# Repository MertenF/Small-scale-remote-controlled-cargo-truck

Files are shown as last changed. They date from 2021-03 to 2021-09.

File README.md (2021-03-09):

# Small-scale-remote-controlled-cargo-truck
Maarten Herremans & Merten Fermont

## Omschrijving
Een op afstand bestuurbare cargo truck waarmee een bak bier vervoerd kan worden.
De afstandsbediening en de truck zelf zijn de 2 grote blokken van het project. Beiden zijn gecentreerd rond de STM32F303R68T microcontroller.

## Truck
De truck beweegt zich door middel van 2 BLDC motoren en stuurt met een servo motor.
Er zijn voor en achterlichten aanwezig voor in het donker, samen met pinkers. Om in het donker goed te zien waar de truck rijd is er powerled als fare voorzien. Een toeter is ook voorzien.
Dit zal allemaal gevoed worden door een 5s13p batterijpack van lithiumcellen, beveiligd met een BMS.

## Afstandsbediening
Het afstandsbediening bevat 2 joysticks om gas te geven of te remmen en te sturen. Een aantal drukknoppen om de lichten te bedienen en een rotary encoder om de helderheid van de fare in te stellen.
De communicatie gebeurd op de 2.4GHz band met de NRF24L01+ chip

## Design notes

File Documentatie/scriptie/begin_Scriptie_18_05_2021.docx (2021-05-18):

# Small-scale Remote Controlled RC Car

# Voorwoord

# Inleiding

Het doel van het project is om een klein transport wagentje en een afstandsbediening hiervoor zelf te maken. Het proces zal voornamelijk het design van de verschillende PCB’s inhouden en hierna de software implementatie.

# Blokschemas

## Controller

De inputs van de controller zijn een aantal knoppen voor de verschillende functies.
De joysticks dienen voor te kunnen sturen.
De Potmeter kan een

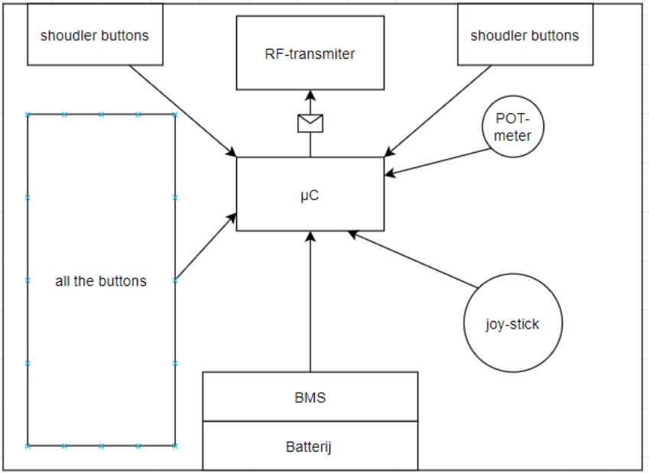
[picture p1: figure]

Figuur 1: blokschema afstandsbediening

## Truck

De main PCB bevind zich op de truck. Hiervan gaan nog de lichten op aparte kleinere PCBtjes komen. Deze licht PCBtjes zijn 4 keer hetzelfde buiten de kleur van de LED.
De main PCB bestaat voornamelijk uit het power delivery systeem met de 5 buckconverters en de BMS.

De ESC is en aparte module waarvan der power van de BMS wordt aangesloten en de signaal kabel van aan de STM µC.

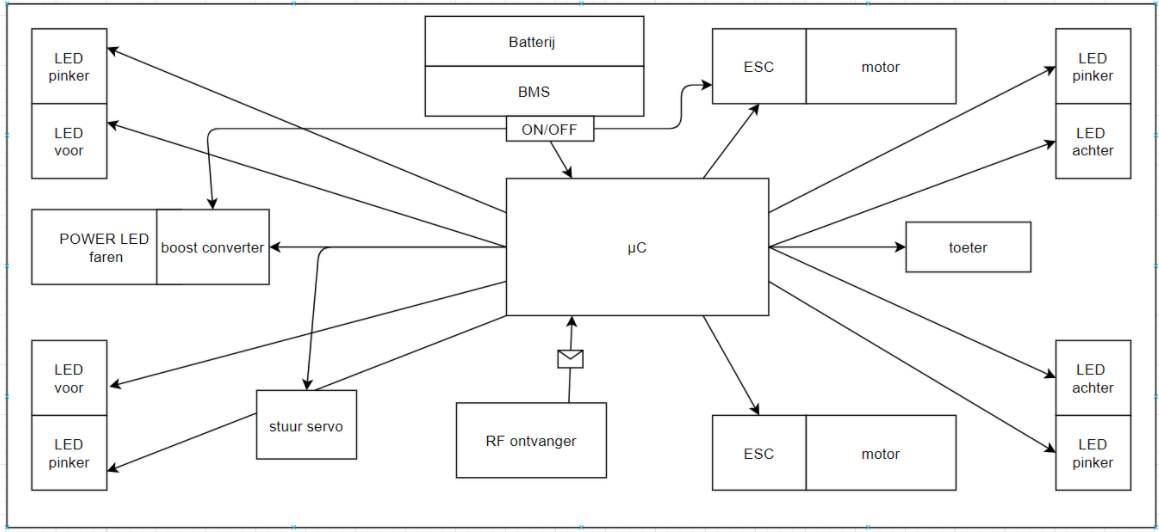
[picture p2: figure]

Figuur 2: blokschema truck

## Spanning niveaus

Er zijn 5 verschillende spanning niveaus nodig voor alle verschillende componenten.
Hierdoor zullen we 4 verschillende Bucks nodig hebben op het main board.

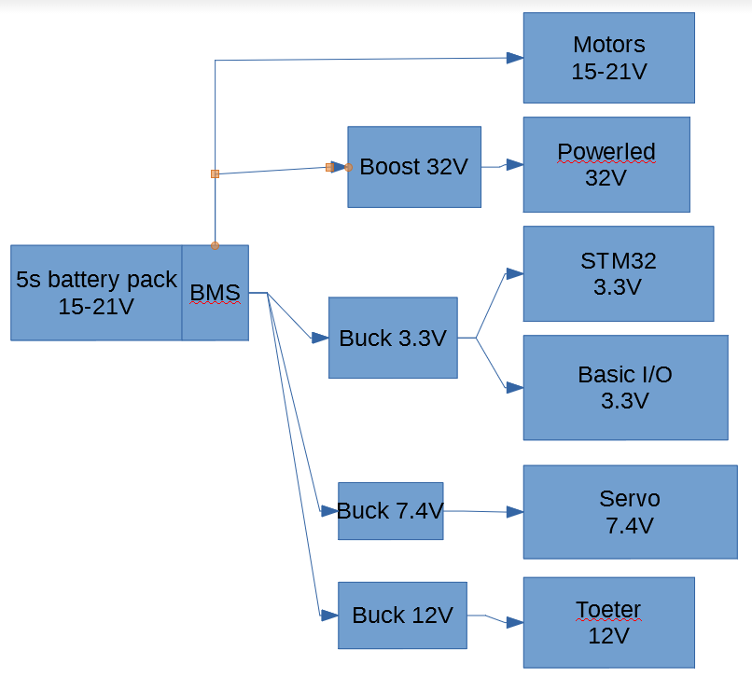
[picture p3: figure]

Figuur 3: blokschema voltage levels

# Hardware

## Schematics

### Electrical

In dit hoofdstuk bevinden zich alle elektrische schemas voor de verschillende PCB’s

#### Controller

De afstands bediening moet alle inputs van de gebruiker inlezen en dan verzenden naar de PCB in de truck.

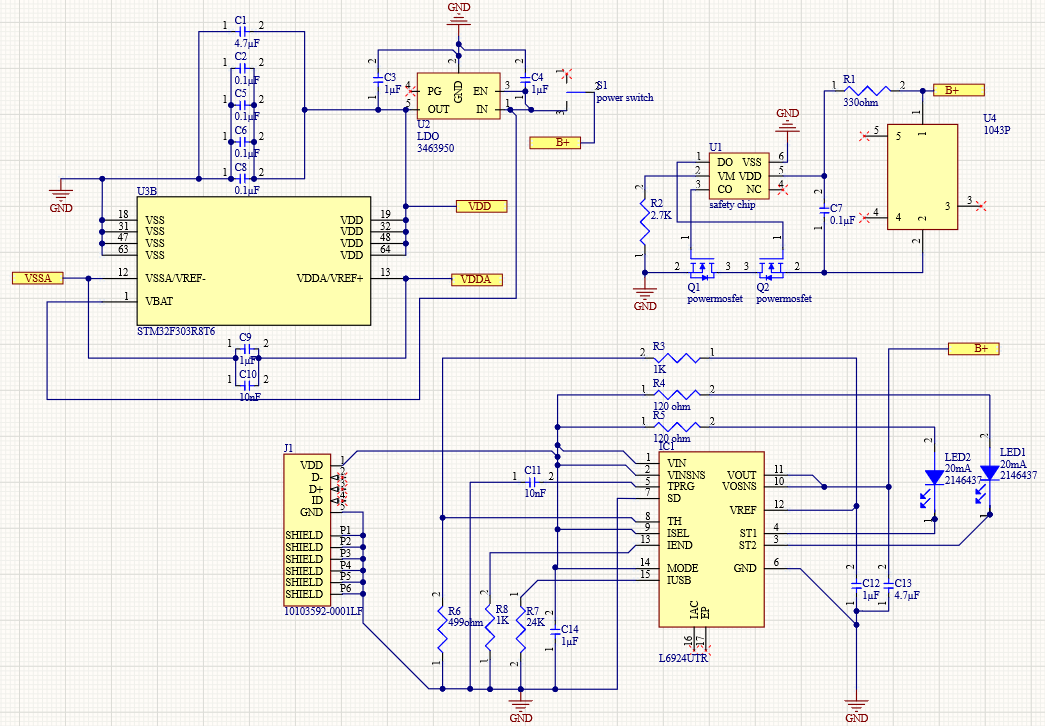
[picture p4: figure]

Figuur 4: afstandsbediening power schema

Op het power schema is het power deel van de STM32F3 aan de linkerkant.
Rechts vanboven bevind zich de batterij en de BMS chip.
vanonder links is de micro USB poort en rechts vanonder is de oplader chip voor de batterij.
Er zijn feedback LED’s rechts vanonder die aangeven wat de oplaad status is.

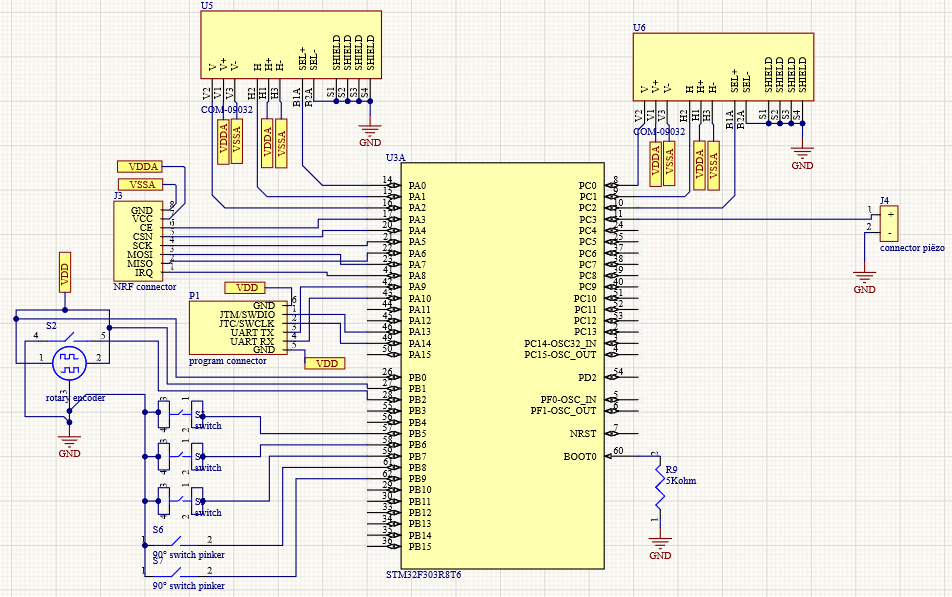
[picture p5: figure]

Figuur 5: afstandsbediening Input en Output

Het main input schema bevat al de GPIO aansluitingen aan de STM plus de nodige rand componenten.

#### Truck

### PCB

#### Controller

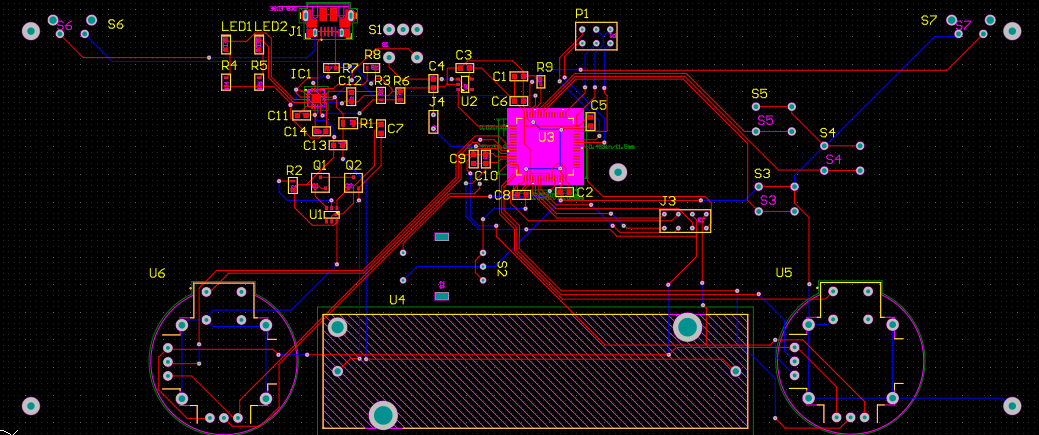
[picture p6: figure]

Figuur 6: PCB afstandsbediening

Links en rechts van onder bevinden zich de joysticks. Deze bevinden zich op deze locatie zodat ze ergonomisch goed zitten. Hetzelfde voor de schouder knoppen links en rechts vanboven.
De condensatoren staan valk naast de IC’s voor minimale EMS.
De batterij houder aan de onderkant had verticaal aan de achterkant geplaatst kunnen worden dit had veel plaats kunnen besparen en ervoor kunnen zorgen dat er veel minder open ruimte is.

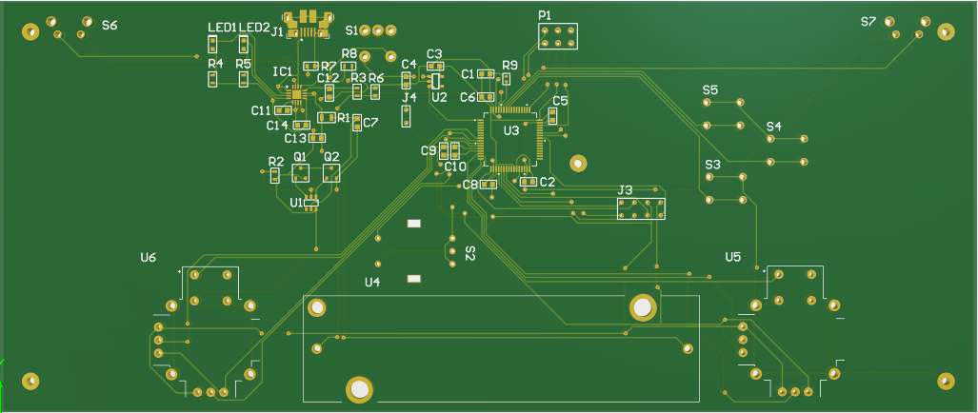
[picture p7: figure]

Figuur 7: 3D board layout afstandsbediening

#### Truck

#### Lichten

## RF module

NRF24L01+

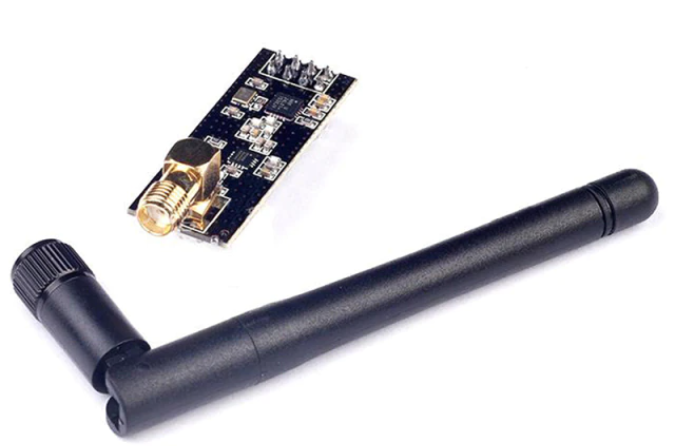
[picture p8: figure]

Voor de draadloze communicatie op 2.4GHz

## Micro controler

STM32F303R8T6

## Drive

### ESC

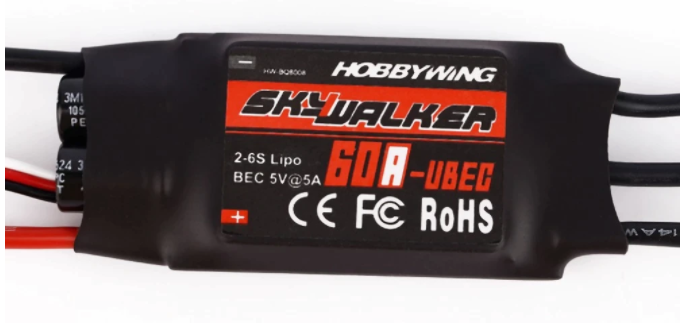
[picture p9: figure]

Specificities:
Constante Stroom: 60A
Burst Stroom (>10s): 80A
spanning: 2s-6s Lipo

### Motor

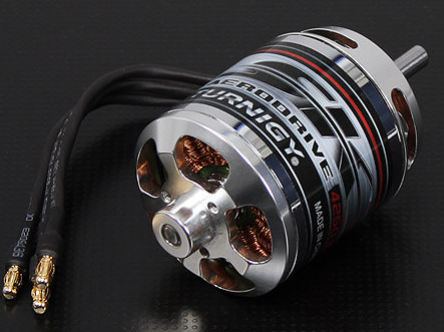
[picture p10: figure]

Specificities:
spanning: 4 ~ 5S Lipo
RPM / V: 410kv
interne weerstand: 0,026 Ohm
Max amperage: 55A
Max Power: 1310W

### Servo

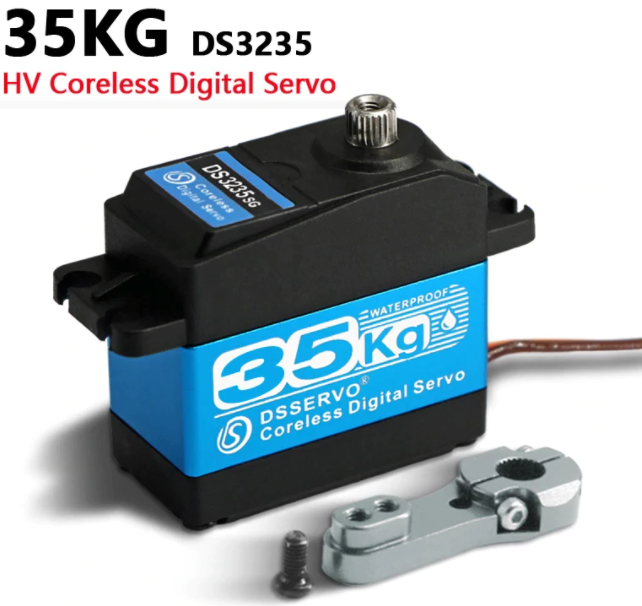
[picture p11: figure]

Spanning: 7.4 volt
rust stroom: 5mA
piek stroom: 2.3A
piek gewicht: 35 kilo

## Mechanische realisatie

### Band overbrenging

Ratio 1:4

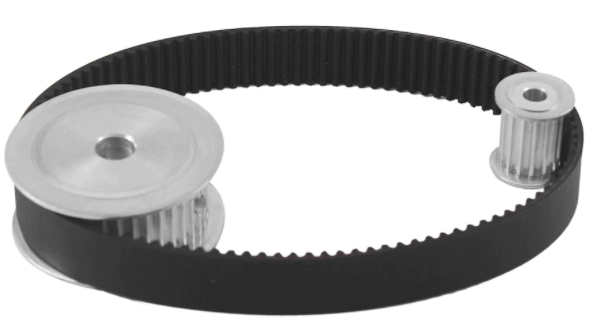
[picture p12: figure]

### Wielen

1/8 schaal wielen.

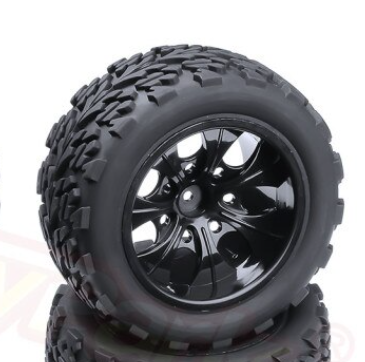
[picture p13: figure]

### Behuizing

# Software

## Testing modules

## Flowchart

## Logic

## I/O

### PWM

### I²C SPI

### RF

Eigen protocol
voor langere range dan enhanced shockburst

# Besluit

# Datasheets

# Bronnen

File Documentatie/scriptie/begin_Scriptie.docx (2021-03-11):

# Small-scale Remote Controlled RC Car

# Voorwoord

# inleiding

# Blokschemas

## Controller


## Truck


## Voltage levels


# Hardware

## Schematics

### Electrical

#### Controller

#### Truck

### PCB

#### Controller

#### Truck

### CAD

#### Controller

#### Truck

## RF module

NRF24L01+

## Micro controler

STM32F303R8T6

## Drive

### ESC

### Motor

### Servo

## Mechanische realisatie

### Band overbrenging

### Wielen

### Hexdrive

### Behuizing

# Software

## Testing modules

## Flowchart

## Logic

## I/O

### PWM

### I²C SPI

### RF

Eigen protocol
voor langere range dan enhanced shockburst

# Besluit

# Datasheets

# Bronnen

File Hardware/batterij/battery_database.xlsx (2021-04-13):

BATTERIJ | CHARGE Mah [@1.5A] | discharge [mAh@2A] | charging mohm start | charging mohm end | opmerking
A1 | 1328 | 1339 | 41 | 32
A2 | 1333 | 1314 | 49 | 28
A3 | 1319 | 1314 | 51 | 40
A4 | 1313 | 1315 | 49 | 30
A5 | 1315 | 1303 | 53 | 33
A6 | 1298 | 1319 | 35 | 27
A7 | 1268 | 1315 | 47 | 36 | cell 2de poging
A8 | 1260 | 1304 | 43 | 35
A9 | 1229 | 1306 | 43 | 34
B1 | 1241 | 1330 | 44 | 34
B2 | 1262 | 1299 | 44 | 32
B3 | 1272 | 1319 | 43 | 33 | in 2keer opegeladen
B4 | 1244 | 1276 | 41 | 32 | cell 2de poging
B5 | 1249 | 1275 | 48 | 37
B6 | 1244 | 1271 | 44 | 34
B7 | 1253 | 1281 | 36 | 28
B8 | 1254 | 1284 | 40 | 31
B9 | 1242 | 1266 | 48 | 34
C1 | 1247 | 1272 | 34 | 34
C2 | 1220 | 1274 | 50 | 28
C3 | 1270 | 1308 | 49 | 37
C4 | 1257 | 1291 | 49 | 37
C5 | 1258 | 1291 | 49 | 37
C6 | 1270 | 1298 | 40 | 31
C7 | 1259 | 1306 | 49 | 36
C8 | 1250 | 1285 | 43 | 34
C9 | 1271 | 1303 | 47 | 37
D1 | 1268 | 1302 | 46 | 36
D2 | 1299 | 1285 | 45 | 35
D3 | 1305 | 1295 | 52 | 32
D4 | 1248 | 1291 | 51 | 36
D5 | 1248 | 1299 | 46 | 36
D6 | 1304 | 1290 | 44 | 34
D7 | 1330 | 1303 | 43 | 34
D8 | 1266 | 1281 | 38 | 30
D9 | 1272 | 1296 | 39 | 31
E1 | 1262 | 1279 | 40 | 30
E2 | 1272 | 1293 | 40 | 30
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

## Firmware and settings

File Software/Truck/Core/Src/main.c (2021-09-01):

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
/* Includes ------------------------------------------------------------------*/
#include "main.h"

/* USER CODE BEGIN Includes */
#include <stdio.h>
#include <errno.h>
#include <sys/stat.h>
#include <sys/times.h>
#include <sys/unistd.h>

#include <stdbool.h>
/* USER CODE END Includes */

SPI_HandleTypeDef hspi2;
SPI_HandleTypeDef hspi3;

TIM_HandleTypeDef htim3;
TIM_HandleTypeDef htim4;

UART_HandleTypeDef huart2;
UART_HandleTypeDef huart3;

/* USER CODE BEGIN PV */
// NRF commando's
const uint8_t R_REGISTER = 0b00000000;
const uint8_t W_REGISTER = 0b00100000;
const uint8_t R_RX_PAYLOAD = 0b01100001;
const uint8_t W_TXPAYLOAD = 0b10100000;
const uint8_t FLUSH_TX = 0b11100001;
const uint8_t FLUSH_RX = 0b11100010;
const uint8_t REUSE_TX_PL = 0b11100011;
const uint8_t R_RX_PL_WID = 0b01100000;
const uint8_t W_ACK_PAYLOAD = 0b10101000;
const uint8_t W_TX_PAYLOAD_NOACK = 0b10110000;
const uint8_t NOP = 0b11111111;

// NRF registers
const uint8_t CONFIG = 0x00;
const uint8_t EN_AA = 0x01;
const uint8_t EN_RXADDR = 0x02;
const uint8_t SETUP_AW = 0x03;
const uint8_t SETUP_RETR = 0x04;
const uint8_t RF_CH = 0x05;
const uint8_t RF_SETUP = 0x06;
const uint8_t STATUS = 0x07;
const uint8_t OBSERVE_TX = 0x08;
const uint8_t RPD = 0x09;
const uint8_t RX_ADDR_P0 = 0x0A;
const uint8_t RX_ADDR_P1 = 0x0B;
const uint8_t RX_ADDR_P2 = 0x0C;
const uint8_t RX_ADDR_P3 = 0x0D;
const uint8_t RX_ADDR_P4 = 0x0E;
const uint8_t RX_ADDR_P5 = 0x0F;
const uint8_t TX_ADDR = 0x10;
const uint8_t RX_PW_P0 = 0x11;
const uint8_t RX_PW_P1 = 0x12;
const uint8_t RW_PW_P1 = 0x13;
const uint8_t RX_PW_P3 = 0x14;
const uint8_t RX_PW_P4 = 0x15;
const uint8_t RX_PW_P5 = 0x16;
const uint8_t FIFO_STATUS = 0x17;
const uint8_t DYNPD = 0x1C;
const uint8_t FEATURE = 0x1D;

#define servoMinAbs 1565 //minimum waarde servo
#define servoMaxAbs 7826
const uint32_t motorMin = 3130; //minimum waarde motor
const uint32_t motorMax = 6260;
uint32_t servoMin = (servoMinAbs+servoMaxAbs)/2-1000;
uint32_t servoMax = (servoMinAbs+servoMaxAbs)/2+1000;
uint8_t RecData[32] = {0};
uint8_t counter = 0;

struct IOs {
	bool Left_Button;
	bool Up_Button;
	bool Down_Button;
	bool Rotary_Button;
	bool Joy2_Button;
	bool FrontLeft_Button;
	bool FrontRight_Button;
	uint8_t Joy1_UpDown;
	uint8_t Joy2_UpDown;
	uint8_t Joy2_LeftRight;
} Status_IO;

uint8_t rxd[10] = {0};
uint8_t UART3_rxBuffer[13] = {0};

/* USER CODE END PV */

void SystemClock_Config(void);
static void MX_GPIO_Init(void);
static void MX_TIM3_Init(void);
static void MX_TIM4_Init(void);
static void MX_SPI2_Init(void);
static void MX_SPI3_Init(void);
static void MX_USART2_UART_Init(void);
static void MX_USART3_UART_Init(void);
/* USER CODE BEGIN PFP */
void Write8_Register_NRF(uint8_t, uint8_t);
uint8_t Read8_Register_NRF(uint8_t);
void CSN_Select(void);
void CSN_Deselect(void);
void Send_Data(uint8_t*);
void NRF_Setup(void);
void WriteX_Register_NRF(uint8_t, uint8_t*, uint8_t);
void Data_Receive(uint8_t*);
uint8_t isDataAvailable (uint8_t);

void Set_Servo_Angle(uint8_t);
void Set_Motor_Speed(uint8_t);
void Print_IO(void);

/* USER CODE END PFP */

/* USER CODE BEGIN 0 */
int _write(int file, char *ptr, int len) {
    HAL_StatusTypeDef xStatus;
    switch (file) {
    case STDOUT_FILENO: /*stdout*/
		xStatus = HAL_UART_Transmit(&huart2, (uint8_t*)ptr, len, HAL_MAX_DELAY);
		if (xStatus != HAL_OK) {
			errno = EIO;
			return -1;
		}
        break;
    case STDERR_FILENO: /* stderr */
		xStatus = HAL_UART_Transmit(&huart2, (uint8_t*)ptr, len, HAL_MAX_DELAY);
		if (xStatus != HAL_OK) {
			errno = EIO;
			return -1;
		}
        break;
    default:
        errno = EBADF;
        return -1;
    }
    return len;
}
/* USER CODE END 0 */

/**
  * @brief  The application entry point.
  * @retval int
  */
int main(void)
{
  /* MCU Configuration--------------------------------------------------------*/

  /* Reset of all peripherals, Initializes the Flash interface and the Systick. */
  HAL_Init();

  /* Configure the system clock */
  SystemClock_Config();

  /* Initialize all configured peripherals */
  MX_GPIO_Init();
  MX_TIM3_Init();
  MX_TIM4_Init();
  MX_SPI2_Init();
  MX_SPI3_Init();
  MX_USART2_UART_Init();
  MX_USART3_UART_Init();
  /* USER CODE BEGIN 2 */

  printf("starting up: ");


  HAL_UART_Receive_IT(&huart3, UART3_rxBuffer, 13);


  HAL_TIM_PWM_Start(&htim3, TIM_CHANNEL_1); //servo
  HAL_TIM_PWM_Start(&htim3, TIM_CHANNEL_2); //motor 1
  HAL_TIM_PWM_Start(&htim3, TIM_CHANNEL_3); //motor 2

  TIM3->CCR1 = (servoMin+servoMax)/2; //servo in het midden zetten
  TIM3->CCR2 = motorMin; //motors minimum power geven
  TIM3->CCR3 = motorMin;


  HAL_Delay(400); //ESC heeft bij opstarten een tijdje minimum signaal nodig
  //NRF_Setup();


  //HAL_TIM_PWM_Start(&htim4, TIM_CHANNEL_1); //toeter
  //HAL_TIM_PWM_Stop(&htim4, TIM_CHANNEL_1);
  //TIM4->CCR1 = 50; //0% duty cycle

  /* USER CODE END 2 */

  /* Infinite loop */
  /* USER CODE BEGIN WHILE */
  while (1)
  {
	  HAL_Delay(80);
	  //printf("\r\nwhile loop truck: %02X\r\n", counter++);


	  //Print_IO();


	  Set_Motor_Speed(Status_IO.Joy1_UpDown);
	  Set_Servo_Angle(Status_IO.Joy2_LeftRight);


	  if(Status_IO.Down_Button) {
		  //TIM4->CCR1 = 50;
	  } else {
		  //TIM4-> CCR1 = 0;
	  }
	  //get data
	  //setup data


    /* USER CODE END WHILE */

    /* USER CODE BEGIN 3 */
  }
  /* USER CODE END 3 */
}

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
/* USER CODE BEGIN 4 */

uint8_t Count13(uint8_t val) {
	if (val<13) {
		return val;
	} else {
		return (val-13);
	}
}

void HAL_UART_RxCpltCallback(UART_HandleTypeDef *huart)
{
	for(uint8_t i = 0; i<13; i++) {
		printf("%u ", UART3_rxBuffer[i]);
	} printf("\r\n");

	uint8_t i = 0;
	while (UART3_rxBuffer[Count13(i)] != 0x41 || UART3_rxBuffer[Count13(i+1)] != 0x41 || UART3_rxBuffer[Count13(i+2)] != 0x41) {
		i++;
	}
	//printf("bytes shifted: %u", i);

	Status_IO.Left_Button = UART3_rxBuffer[Count13(i+3)];
	Status_IO.Up_Button = UART3_rxBuffer[Count13(i+4)];
	Status_IO.Down_Button = UART3_rxBuffer[Count13(i+5)];
	Status_IO.Rotary_Button = UART3_rxBuffer[Count13(i+6)];
	Status_IO.Joy2_Button = UART3_rxBuffer[Count13(i+7)];
	Status_IO.FrontLeft_Button = UART3_rxBuffer[Count13(i+8)];
	Status_IO.FrontRight_Button = UART3_rxBuffer[Count13(i+9)];
	Status_IO.Joy1_UpDown = UART3_rxBuffer[Count13(i+10)];
	Status_IO.Joy2_UpDown = UART3_rxBuffer[Count13(i+11)];
	Status_IO.Joy2_LeftRight = UART3_rxBuffer[Count13(i+12)];

	//Print_IO();

    HAL_UART_Receive_IT(&huart3, UART3_rxBuffer, 13);
}

void Print_IO() {
	printf("IO status:\r\n");
	printf("Buttons: LB=%d, UB=%d, DB=%d, RB=%d, J2B=%d\r\n",
			Status_IO.Left_Button,
			Status_IO.Up_Button,
			Status_IO.Down_Button,
			Status_IO.Rotary_Button,
			Status_IO.Joy2_Button);

	printf("ADC: 1-UD=%u, 2-UD=%u, 2-LR=%u\r\n",
			Status_IO.Joy1_UpDown,
			Status_IO.Joy2_UpDown,
			Status_IO.Joy2_LeftRight);
}

void Read_Data() {
	//fill
}


void Set_Motor_Speed(uint8_t speed) {
	uint32_t signal = (motorMax-motorMin)*speed/255+motorMin;

	if (signal<motorMin) {
		printf("Motor signal to low: %lu\r\n", signal);
		signal = motorMin;
	} else if (signal > motorMax) {
		printf("Motor signal to high: %lu\r\n", signal);
		signal = motorMax;
	}

	TIM3->CCR2 = signal;
	TIM3->CCR3 = signal;
}

void Set_Servo_Angle(uint8_t angle) {
	uint32_t signal = (servoMax-servoMin)*angle/255+servoMin;

	if (signal<servoMin) {
		printf("Servo signal to low: %lu\r\n", signal);
		signal = servoMin;
	} else if (signal > servoMax) {
		printf("Servo signal to high: %lu\r\n", signal);
		signal = servoMax;
	}

	TIM3->CCR1 = signal;
}

uint8_t Read8_Register_NRF(uint8_t reg) {
	uint8_t data = 0;

	CSN_Select();
	HAL_SPI_Transmit(&hspi2, &reg, 1, 100);
	while(HAL_SPI_GetState(&hspi2) != HAL_SPI_STATE_READY);
	HAL_SPI_Receive(&hspi2, &data, 1, 100);
	CSN_Deselect();

	printf("Receive %02X: %02X\r\n", reg, data);
	return 0;
}

void Write8_Register_NRF(uint8_t reg, uint8_t data) {
	uint8_t buf[2];

	buf[0] = reg|W_REGISTER;
	buf[1] = data;

	CSN_Select();
	HAL_SPI_Transmit(&hspi2, buf, 2, 1000);
	CSN_Deselect();
}

void WriteX_Register_NRF(uint8_t reg, uint8_t *data, uint8_t size) {
	CSN_Select();

	uint8_t cmd = reg|W_REGISTER;

	HAL_SPI_Transmit(&hspi2, &cmd, 1, 100);
	HAL_SPI_Transmit(&hspi2, data, size, 1000);
	/*
	uint8_t sent[1+size];
	uint8_t cmd = reg|W_REGISTER;
	sent[0] = cmd;

	HAL_StatusTypeDef result;
	result = HAL_SPI_Transmit(&hspi2, sent, size+1, 1000);
	printf("Result: %u\r\n", result);
//	HAL_SPI_Transmit(&hspi1, &cmd, 1, 100);
//	HAL_SPI_Transmit(&hspi1, data, size, 1000);
*/



	CSN_Deselect();
}

uint8_t* ReadX_Register_NRF(uint8_t reg, uint8_t size) {
	uint8_t data[32] = {0};

	CSN_Select();
	HAL_SPI_Transmit(&hspi2, &reg, 1, 100);
	HAL_SPI_Receive(&hspi2, data, size, 1000);
	CSN_Deselect();

	for (uint8_t i = 0; i<size; i++) {
		printf("%02X ", i);
	}
	printf("\r\n");
	return 0;
}

void Send_Cmd(uint8_t cmd) {
	CSN_Select();
	HAL_SPI_Transmit(&hspi2, &cmd, 1, 100);
	CSN_Deselect();
}

void Send_Data(uint8_t *data) {

	uint8_t cmd = W_TXPAYLOAD;
	CSN_Select();
	HAL_SPI_Transmit(&hspi2, &cmd, 1, 100);
	HAL_SPI_Transmit(&hspi2, data, 32, 1000);
	CSN_Deselect();

	printf("observe tx");
	Read8_Register_NRF(OBSERVE_TX);

	printf("fifo status");
	uint8_t fifostatus = Read8_Register_NRF(FIFO_STATUS);
	// check the fourth bit of FIFO_STATUS to know if the TX fifo is empty
	if ((fifostatus&(1<<4)) && (!(fifostatus&(1<<3))))
		{
			printf("Fifo full\r\n");
			cmd = FLUSH_TX;
			Send_Cmd(cmd);
		} else {
			//printf("empty\r\n");
		}
}


uint8_t isDataAvailable (uint8_t pipenum)
{
	printf("Status ");
	uint8_t status = Read8_Register_NRF(STATUS);
	printf("FIFO_STATUS ");
	Read8_Register_NRF(FIFO_STATUS);

	if ((status&(1<<6))||1) //&&(status&(pipenum<<1))
	{

		Write8_Register_NRF(STATUS, (1<<6));

		return 1;
	}

	return 0;
}

void NRF_Setup() {
	printf("\r\n\r\nBegin setup NRFFF\r\n");
	CSN_Deselect();
	HAL_GPIO_WritePin(nrf_ce_GPIO_Port, nrf_ce_Pin, GPIO_PIN_RESET);

	HAL_Delay(50);

	Read8_Register_NRF(SETUP_AW);
	Write8_Register_NRF(SETUP_AW, 0x03);
	Read8_Register_NRF(SETUP_AW);

	Write8_Register_NRF(CONFIG, 0);
	Read8_Register_NRF(CONFIG);
	Write8_Register_NRF(CONFIG, 0b10001011); //power up bit
	Read8_Register_NRF(CONFIG);
	HAL_Delay(10);

	Read8_Register_NRF(RF_CH);
	Write8_Register_NRF(RF_CH, 15); //zet channel naar 15
	Read8_Register_NRF(RF_CH);

	Read8_Register_NRF(RF_SETUP);
	Write8_Register_NRF(RF_SETUP, 0x0E);  //set RF_DR_LOW (250kbit) in RF_SETUP 0b00101110
	Read8_Register_NRF(RF_SETUP);

	Write8_Register_NRF(EN_AA, 1);
	Write8_Register_NRF(SETUP_RETR, 0b01001111);

	ReadX_Register_NRF(TX_ADDR, 5);
	uint8_t addr[6] = "00001";
	WriteX_Register_NRF(TX_ADDR, addr, 5);
	ReadX_Register_NRF(TX_ADDR, 5);

	ReadX_Register_NRF(RX_ADDR_P0, 5);
	WriteX_Register_NRF(RX_ADDR_P0, addr,5);
	ReadX_Register_NRF(RX_ADDR_P0, 5);

	Read8_Register_NRF(EN_RXADDR);
	Write8_Register_NRF(EN_RXADDR, 1);
	Read8_Register_NRF(EN_RXADDR);

	Read8_Register_NRF(RX_PW_P0);
	Write8_Register_NRF(RX_PW_P0, 32);
	Read8_Register_NRF(RX_PW_P0);

	printf("Status: ");
	uint8_t sta = Read8_Register_NRF(STATUS);
	Write8_Register_NRF(STATUS, sta);
	Read8_Register_NRF(STATUS);


	//set nrf ce voor te enabled te gaan
	HAL_GPIO_WritePin(nrf_ce_GPIO_Port, nrf_ce_Pin, GPIO_PIN_SET);
}

void Data_Receive (uint8_t *data)
{
	CSN_Select();

	uint8_t cmdtosend = R_RX_PAYLOAD;

	HAL_SPI_Transmit(&hspi2, &cmdtosend, 1, 100);
	HAL_SPI_Receive(&hspi2, data, 32, 1000);

	CSN_Deselect();

	HAL_Delay(1);

	//Send_Cmd(FLUSH_RX);
}


void CSN_Select() {
	HAL_GPIO_WritePin(csn_GPIO_Port, csn_Pin, GPIO_PIN_RESET);
}

void CSN_Deselect() {
	HAL_GPIO_WritePin(csn_GPIO_Port, csn_Pin, GPIO_PIN_SET);
}
/* USER CODE END 4 */
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


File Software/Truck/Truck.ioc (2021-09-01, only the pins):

Mcu.UserName=STM32F303RETx
PA11.Signal=S_TIM4_CH1
PA13.GPIO_Label=TMS
PA13.Signal=SYS_JTMS-SWDIO
PA14.GPIO_Label=TCK
PA14.Signal=SYS_JTCK-SWCLK
PA2.GPIO_Label=USART_TX
PA2.Signal=USART2_TX
PA3.GPIO_Label=USART_RX
PA3.Signal=USART2_RX
PA4.Signal=S_TIM3_CH2
PA5.GPIO_Label=LD2 [Green Led]
PA5.Signal=GPIO_Output
PA6.Signal=S_TIM3_CH1
PB0.Signal=S_TIM3_CH3
PB10.Signal=USART3_TX
PB11.Signal=USART3_RX
PB13.Signal=SPI2_SCK
PB14.Signal=SPI2_MISO
PB15.Signal=SPI2_MOSI
PB3.GPIO_Label=SWO
PB3.Signal=SYS_JTDO-TRACESWO
PB4.Signal=GPIO_Output
PB5.Signal=GPIO_Output
PB6.Signal=GPIO_Output
PB7.Signal=GPIO_Output
PC10.Signal=SPI3_SCK
PC11.Signal=SPI3_MISO
PC12.Signal=SPI3_MOSI
PC13.GPIO_Label=B1 [Blue PushButton]
PC13.Signal=GPXTI13
PC14-OSC32_IN.Signal=RCC_OSC32_IN
PC15-OSC32_OUT.Signal=RCC_OSC32_OUT
PC6.GPIO_Label=csn
PC6.Signal=GPIO_Output
PC7.GPIO_Label=nrf_ce
PC7.Signal=GPIO_Output
PF0-OSC_IN.Signal=RCC_OSC_IN
PF1-OSC_OUT.Signal=RCC_OSC_OUT

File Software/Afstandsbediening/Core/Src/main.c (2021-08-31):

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
/* Includes ------------------------------------------------------------------*/
#include "main.h"

/* USER CODE BEGIN Includes */
#include <stdio.h>
#include <errno.h>
#include <sys/stat.h>
#include <sys/times.h>
#include <sys/unistd.h>

#include <stdbool.h>
/* USER CODE END Includes */

ADC_HandleTypeDef hadc1;
DMA_HandleTypeDef hdma_adc1;

SPI_HandleTypeDef hspi1;

UART_HandleTypeDef huart1;

/* USER CODE BEGIN PV */

// NRF commando's
const uint8_t R_REGISTER = 0b00000000;
const uint8_t W_REGISTER = 0b00100000;
const uint8_t R_RX_PAYLOAD = 0b01100001;
const uint8_t W_TXPAYLOAD = 0b10100000;
const uint8_t FLUSH_TX = 0b11100001;
const uint8_t FLUSH_RX = 0b11100010;
const uint8_t REUSE_TX_PL = 0b11100011;
const uint8_t R_RX_PL_WID = 0b01100000;
const uint8_t W_ACK_PAYLOAD = 0b10101000;
const uint8_t W_TX_PAYLOAD_NOACK = 0b10110000;
const uint8_t NOP = 0b11111111;

// NRF registers
const uint8_t CONFIG = 0x00;
const uint8_t EN_AA = 0x01;
const uint8_t EN_RXADDR = 0x02;
const uint8_t SETUP_AW = 0x03;
const uint8_t SETUP_RETR = 0x04;
const uint8_t RF_CH = 0x05;
const uint8_t RF_SETUP = 0x06;
const uint8_t STATUS = 0x07;
const uint8_t OBSERVE_TX = 0x08;
const uint8_t RPD = 0x09;
const uint8_t RX_ADDR_P0 = 0x0A;
const uint8_t RX_ADDR_P1 = 0x0B;
const uint8_t RX_ADDR_P2 = 0x0C;
const uint8_t RX_ADDR_P3 = 0x0D;
const uint8_t RX_ADDR_P4 = 0x0E;
const uint8_t RX_ADDR_P5 = 0x0F;
const uint8_t TX_ADDR = 0x10;
const uint8_t RX_PW_P0 = 0x11;
const uint8_t RX_PW_P1 = 0x12;
const uint8_t RW_PW_P1 = 0x13;
const uint8_t RX_PW_P3 = 0x14;
const uint8_t RX_PW_P4 = 0x15;
const uint8_t RX_PW_P5 = 0x16;
const uint8_t FIFO_STATUS = 0x17;
const uint8_t DYNPD = 0x1C;
const uint8_t FEATURE = 0x1D;

const uint16_t ADC_MIN = 0;
const uint16_t ADC_MAX = 4090;

uint32_t adc_results[4];
uint8_t count = 0;

struct CalValADC {
	uint16_t Joy1_UpDown;
	uint16_t Joy2_UpDown;
	uint16_t Joy2_LeftRight;
} defaultAdc;

struct IOs {
	bool Left_Button;
	bool Up_Button;
	bool Down_Button;
	bool Rotary_Button;
	bool Joy2_Button;
	bool FrontLeft_Button;
	bool FrontRight_Button;
	uint8_t Joy1_UpDown;
	uint8_t Joy2_UpDown;
	uint8_t Joy2_LeftRight;
} Status_IO;

/* USER CODE END PV */

void SystemClock_Config(void);
static void MX_GPIO_Init(void);
static void MX_DMA_Init(void);
static void MX_ADC1_Init(void);
static void MX_SPI1_Init(void);
static void MX_USART1_UART_Init(void);
/* USER CODE BEGIN PFP */

void Write8_Register_NRF(uint8_t, uint8_t);
uint8_t Read8_Register_NRF(uint8_t);
void CSN_Select(void);
void CSN_Deselect(void);
void Send_Data(uint8_t*);
void NRF_Setup(void);
void WriteX_Register_NRF(uint8_t, uint8_t*, uint8_t);
void Read_Buttons(void);
void Calibrate_ADC(void);
void Print_IO(void);
uint8_t Regulate_ADC_UpDown(uint32_t, uint16_t);
uint8_t Regulate_ADC_LeftRight(uint32_t, uint16_t);

/* USER CODE END PFP */

/* USER CODE BEGIN 0 */
int _write(int file, char *ptr, int len) {
    HAL_StatusTypeDef xStatus;
    switch (file) {
    case STDOUT_FILENO: /*stdout*/
		xStatus = HAL_UART_Transmit(&huart1, (uint8_t*)ptr, len, HAL_MAX_DELAY);
		if (xStatus != HAL_OK) {
			errno = EIO;
			return -1;
		}
        break;
    case STDERR_FILENO: /* stderr */
		xStatus = HAL_UART_Transmit(&huart1, (uint8_t*)ptr, len, HAL_MAX_DELAY);
		if (xStatus != HAL_OK) {
			errno = EIO;
			return -1;
		}
        break;
    default:
        errno = EBADF;
        return -1;
    }
    return len;
}

char uart_buf[50];
int uart_buf_len;
/* USER CODE END 0 */

/**
  * @brief  The application entry point.
  * @retval int
  */
int main(void)
{
  /* MCU Configuration--------------------------------------------------------*/

  /* Reset of all peripherals, Initializes the Flash interface and the Systick. */
  HAL_Init();

  /* Configure the system clock */
  SystemClock_Config();

  /* Initialize all configured peripherals */
  MX_GPIO_Init();
  MX_DMA_Init();
  MX_ADC1_Init();
  MX_SPI1_Init();
  MX_USART1_UART_Init();
  /* USER CODE BEGIN 2 */

  //calbrate de ADC
  HAL_ADCEx_Calibration_Start(&hadc1, ADC_SINGLE_ENDED);
  HAL_ADC_Start_DMA(&hadc1, adc_results, 4);

  //NRF_Setup();
  HAL_Delay(300);
  Calibrate_ADC();
  //printf("started up \r\n");
  /* USER CODE END 2 */

  /* Infinite loop */
  /* USER CODE BEGIN WHILE */
  while (1)
  {
	  //printf("\r\nWhile afstandsbediening %02X\r\n", count++);

	  Read_Buttons();
	  //Print_IO();

	  uint8_t startSequence[3] = {0x42, 0x42, 0x42}; //BBB

	  HAL_UART_Transmit(&huart1, &startSequence, 3, 100);
	  HAL_UART_Transmit(&huart1, &Status_IO, 10, 1000);

	  //HAL_UART_Transmit(&huart1, &stopByte, 1, 100);

	  HAL_Delay(400);

	  /*uint8_t string[32] = "test";
	  printf("Data:%s\r\n", string);
	  	  for (uint8_t i =0; i<32; i++) {
	  		  printf("%02X ", string[i]);
	  	  } printf("\r\n");
	  Send_Data(string);*/

	  //printf("ADC: %lu R-BO:%lu L-BO:%lu L-RL:%lu\r\n", adc_results[0], adc_results[1], adc_results[2], adc_results[3]);

    /* USER CODE END WHILE */

    /* USER CODE BEGIN 3 */
  }
  /* USER CODE END 3 */
}

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
/* USER CODE BEGIN 4 */

void Calibrate_ADC() {
	defaultAdc.Joy1_UpDown = adc_results[1];
	defaultAdc.Joy2_UpDown = adc_results[2];
	defaultAdc.Joy2_LeftRight = adc_results[3];
}

//waardes naar een schaal van 0-255 omrekenen
uint8_t Regulate_ADC_UpDown(uint32_t value, uint16_t defaultt) {
	uint32_t result;
	if (value > defaultt) {
		result = 0;
	} else {
		result = (defaultt-value)*255/(defaultt-ADC_MIN);
	}

	return (uint8_t)result;
}

uint8_t Regulate_ADC_LeftRight(uint32_t value, uint16_t defaultt) {
	uint16_t result;
	if (value < defaultt) { //links
		result = 128-(defaultt-value)*127/(defaultt-ADC_MIN);
	} else { //rechts
		result = (value-defaultt)*127/(ADC_MAX-defaultt)+128;
	}
	return (uint8_t)result;
}

void Read_Buttons() {

	HAL_ADC_Start_DMA(&hadc1, adc_results, 4);

	Status_IO.Left_Button = !HAL_GPIO_ReadPin(button_left_GPIO_Port, button_left_Pin);
	Status_IO.Up_Button = !HAL_GPIO_ReadPin(button_up_GPIO_Port, button_up_Pin);
	Status_IO.Down_Button = ! HAL_GPIO_ReadPin(button_down_GPIO_Port, button_down_Pin);
	Status_IO.Rotary_Button = !HAL_GPIO_ReadPin(rotary_switch_GPIO_Port, rotary_switch_Pin);
	Status_IO.Joy2_Button = !HAL_GPIO_ReadPin(joy2_knop_GPIO_Port, joy2_knop_Pin);

	Status_IO.Joy1_UpDown = Regulate_ADC_UpDown(adc_results[1], defaultAdc.Joy1_UpDown);
	//printf("%u %u \r\n", adc_results[1], defaultAdc.Joy1_UpDown);
	Status_IO.Joy2_UpDown = Regulate_ADC_UpDown(adc_results[2], defaultAdc.Joy2_UpDown);
	//printf("%u %u \r\n", adc_results[2], defaultAdc.Joy2_UpDown);
	Status_IO.Joy2_LeftRight = Regulate_ADC_LeftRight(adc_results[3], defaultAdc.Joy2_LeftRight);
}

void Print_IO() {
	printf("IO status:\r\n");
	printf("Buttons: LB=%d, UB=%d, DB=%d, RB=%d, J2B=%d\r\n",
			Status_IO.Left_Button,
			Status_IO.Up_Button,
			Status_IO.Down_Button,
			Status_IO.Rotary_Button,
			Status_IO.Joy2_Button);

	printf("ADC: 1-UD=%u, 2-UD=%u, 2-LR=%u\r\n",
			Status_IO.Joy1_UpDown,
			Status_IO.Joy2_UpDown,
			Status_IO.Joy2_LeftRight);
}
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

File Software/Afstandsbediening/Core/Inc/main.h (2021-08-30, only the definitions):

#define joy2_ver_Pin GPIO_PIN_0
#define joy2_ver_GPIO_Port GPIOC
#define joy2_hor_Pin GPIO_PIN_1
#define joy2_hor_GPIO_Port GPIOC
#define joy2_knop_Pin GPIO_PIN_2
#define joy2_knop_GPIO_Port GPIOC
#define piezo_Pin GPIO_PIN_3
#define piezo_GPIO_Port GPIOC
#define joy1_knop_Pin GPIO_PIN_0
#define joy1_knop_GPIO_Port GPIOA
#define joy2_horA1_Pin GPIO_PIN_1
#define joy2_horA1_GPIO_Port GPIOA
#define joy1_ver_Pin GPIO_PIN_2
#define joy1_ver_GPIO_Port GPIOA
#define nrf_CE_Pin GPIO_PIN_3
#define nrf_CE_GPIO_Port GPIOA
#define csn_Pin GPIO_PIN_4
#define csn_GPIO_Port GPIOA
#define rotary1_Pin GPIO_PIN_0
#define rotary1_GPIO_Port GPIOB
#define rotary2_Pin GPIO_PIN_1
#define rotary2_GPIO_Port GPIOB
#define rotary_switch_Pin GPIO_PIN_2
#define rotary_switch_GPIO_Port GPIOB
#define SPI1_IRQ_Pin GPIO_PIN_8
#define SPI1_IRQ_GPIO_Port GPIOA
#define button_left_Pin GPIO_PIN_5
#define button_left_GPIO_Port GPIOB
#define button_up_Pin GPIO_PIN_6
#define button_up_GPIO_Port GPIOB
#define button_down_Pin GPIO_PIN_7
#define button_down_GPIO_Port GPIOB
#define button_pinker_links_Pin GPIO_PIN_8
#define button_pinker_links_GPIO_Port GPIOB
#define button_pinker_rechts_Pin GPIO_PIN_9
#define button_pinker_rechts_GPIO_Port GPIOB

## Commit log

2021-03-06 Schema lichten toegevoegd
    Voor of achterlicht samen met pinker. Ieder heeft een eigen buck-converter, bediend over SPI
    [Lichten.PrjPcb, Lichten.SchLib, lichten.SchDoc]
2021-03-08 afstand bediening project
    [PCB_afstand_bediening.PrjPcb, afstandsbediening_library.SchLib, afstandsbediening_main_IO.SchDoc]
2021-03-08 project file van afstandsbediening
    vorige werkte niet nam slecht enkele files mee
    [PCB_afstand_bediening.PrjPcb, afstandsbediening_library.SchLib, afstandsbediening_main_IO.SchDoc]
2021-03-09 fix 3 voor afstands bediening PCB
    [2021-02-22_19-54-40.SchLib, afstandbediening_shematic.SchDoc, afstandsbediening_library.SchLib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]
2021-03-10 Altium bestanden in 1 project onderbrengen
    [2021-02-22_19-54-40.SchLib, Lichten.PrjPcb, Schematic library.SchLib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]
2021-03-11 small merge test group projects
    [2021-02-22_19-54-40.SchLib, Lichten.PrjPcb, Lichten.SchLib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]
2021-03-11 power button fixxed
    [2021-02-22_19-54-40.PcbLib, PcbLib1.PcbLib, afstandbediening_shematic.SchDoc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]
2021-03-11 scriptie aan het toevoegen
2021-03-15 pcb resistor packages
    [PcbLib1.PcbLib, afstandbediening_shematic.SchDoc, afstandsbediening_library.SchLib]
2021-03-16 anotaties in orde op alle schematics
    [Lichten.SchLib, afstandbediening_shematic.SchDoc, afstandsbediening_main_IO.SchDoc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]
2021-03-16 condensator footprins gefixt
    [PcbLib1.PcbLib, afstandbediening_shematic.SchDoc, afstandsbediening_library.SchLib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]
2021-03-16 mosfets en ldo footprints
    [PcbLib1.PcbLib, afstandbediening_shematic.SchDoc, afstandsbediening_library.SchLib]
2021-03-17 footprints
    nog een paar extra,
    voornammelijk throug holes en chips
    [PcbLib1.PcbLib, afstandsbediening_library.SchLib, afstandsbediening_main_IO.SchDoc]
2021-03-19 nog een paar footprints
    [PcbLib1.PcbLib, afstandbediening_shematic.SchDoc, afstandsbediening_library.SchLib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]
2021-03-22 footprints
    troughole switch en pin headers
    [PcbLib1.PcbLib, afstandsbediening_library.SchLib, afstandsbediening_main_IO.SchDoc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]
2021-03-23 basis PCB
    basis begin PCB en nog wat footprints
    [PcbLib1.PcbLib, afstandbediening.PcbDoc, afstandbediening_shematic.SchDoc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]
2021-04-02 batterij update
    [afstandbediening.PcbDoc, afstandsbediening.PrjPcb, battery_database.xlsx]
2021-04-13 final battery update
    [afstandbediening.PcbDoc, battery_database.xlsx]
2021-04-20 school sessie vooruitgang
    schematic afstandsbediening done,
    all footprints done normaly
    [PcbLib1.PcbLib, afstandbediening.PcbDoc, afstandbediening_shematic.SchDoc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]
2021-04-20 pcb design
    routing van alle routes voor afstandsbediening buiten GND plane
    [PcbLib1.PcbLib, afstandbediening.PcbDoc, afstandbediening_shematic.SchDoc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]
2021-04-22 finishing pcb
    [PcbLib1.PcbLib, afstandbediening.PcbDoc]
2021-05-04 temp push
    [afstandbediening.PcbDoc, afstandsbediening_main_IO.SchDoc, lichten.SchDoc]
2021-05-07 update afstandsbediening output files
    [Lichten.PrjPcb, PcbLib1.PcbLib, afstandbediening.PcbDoc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]
2021-05-10 Main schema
    [3.3V.schdoc, 7.4V.schdoc, BMS.SchDoc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]
2021-05-10 lichten footprints en pcb begin
    [Lichten.PrjPcb, Lichten.SchLib, PcbLib1.PcbLib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]
2021-05-11 final update for gerber
    [PcbLib1.PcbLib, Schematic library.SchLib, afstandbediening.PcbDoc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]
2021-05-12 scriptie update
    [BMS.SchDoc, Power sTM.SchDoc, afstandbediening.PcbDoc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]
2021-06-28 PCB 2
    eerste commit van het 2de model van de controller
    [Lichten.PrjPcb, PcbLib1.PcbLib, afstandbediening.PcbDoc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]
2021-06-28 eerste finaal controller 2
    alleen nog externe revieuw nodig voor bestelling van controller 2
    [PcbLib1.PcbLib, afstandbediening.PcbDoc]
2021-07-02 maybe final pre mike
    [afstandbediening.PcbDoc, afstandbediening_shematic.SchDoc]
2021-07-02 issues fix 1
    [PcbLib1.PcbLib, afstandbediening.PcbDoc, afstandbediening_shematic.SchDoc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]
2021-08-30 code, RF niet werkend
    [Afstandsbediening Run.cfg, Lichten.PrjPcb, Truck.cfg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]
2021-08-31 werkende code met AURT communicatie arduino voor RF

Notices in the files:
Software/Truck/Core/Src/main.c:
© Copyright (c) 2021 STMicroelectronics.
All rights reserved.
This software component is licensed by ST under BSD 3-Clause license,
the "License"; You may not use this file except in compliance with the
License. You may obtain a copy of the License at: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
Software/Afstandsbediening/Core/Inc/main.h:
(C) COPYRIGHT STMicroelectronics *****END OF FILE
